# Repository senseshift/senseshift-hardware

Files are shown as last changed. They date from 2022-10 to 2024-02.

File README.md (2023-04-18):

# SenseShift Hardware

> Hardware Schematics for [SenseShift Firmware](https://github.com/senseshift/senseshift-firmware)




## Guides

We provide a variety of different step-by-step guides, made by our community, on our [Documentation](https://senseshift.github.io/guides/getting-started)!

## Schematics

> Each configuration have it's own BOM and wiring diagram

### Haptic Vest

#### X16 Haptic Vest

> Supported devices: **TactSuit X16**

* [X16 Vest with PCA9685](Devices/X16%20Vest/ESP32%20%2B%20PCA9685/)
* [X16 Vest without PCA9685](Devices/X16%20Vest/ESP32%20%2B%20Integrated%20PWM/)

#### X40 Haptic Vest

> Supported devices: **TactSuit X40**, **Tactot**

* [X40 Vest with x2 PCA9685](Devices/X40%20Vest/ESP32%20%2B%20x2%20PCA9685%20%2B%20Integrated%20PWM/)

### Haptic Glove

> Supported devices: **TactGloves**

* [x6 Haptic Glove](Devices/Haptic%20Gloves/ESP32%20%2B%20Integrated%20PWM/)

### Haptic Face Interface

> Supported devices: **Tactal**

* [x6 Facial Interface](Devices/Face%20Interface/ESP32%20+%20Integrated%20PWM/)

### Haptic Forearm Sleeve

> Supported devices: **Tactosy for Arms**

* [x6 Forearm Sleeve](Devices/Forearm%20Sleeves/ESP32%20+%20Integrated%20PWM/)

### Haptic Gauntlet

> Supported devices: **Tactosy for Hands**

* [x3 Hand Gauntlet](Devices/Hand%20Gauntlets/ESP32%20+%20Integrated%20PWM/)

### Haptic Feet Device

> Supported devices: **Tactosy for Feet**

* [x3 Feet Device](Devices/Feet%20Devices/ESP32%20+%20Integrated%20PWM/)

## SenseShift PCBs

PCBs are currently stored in [`feature/haptic-boards`](https://github.com/senseshift/senseshift-hardware/tree/feature/haptic-boards) branch (See PR [#3](https://github.com/senseshift/senseshift-hardware/pull/3)). Those designsed haven't been tested and will be merged, as soon as they are confirmed to be working 100%

## Licenses



Each project directory has it's own `LICENSE` file inside and licensed under corresponding license. Otherwise, if no `LICENSE` file is provided, it is licensed under [CC-BY-SA-4.0](https://creativecommons.org/licenses/by-sa/4.0/) license

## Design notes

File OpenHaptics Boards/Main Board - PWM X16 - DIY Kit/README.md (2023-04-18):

# SenseShift Mainboard *with X16 PWM*

> **Warning**  
> **Disclaimer:** This design is a **functional prototype**, not a complete product. There is absolutely no warranty, and you will make this design at your OWN risk. I will not be responsible for any damages associated with this design.

## Schematic

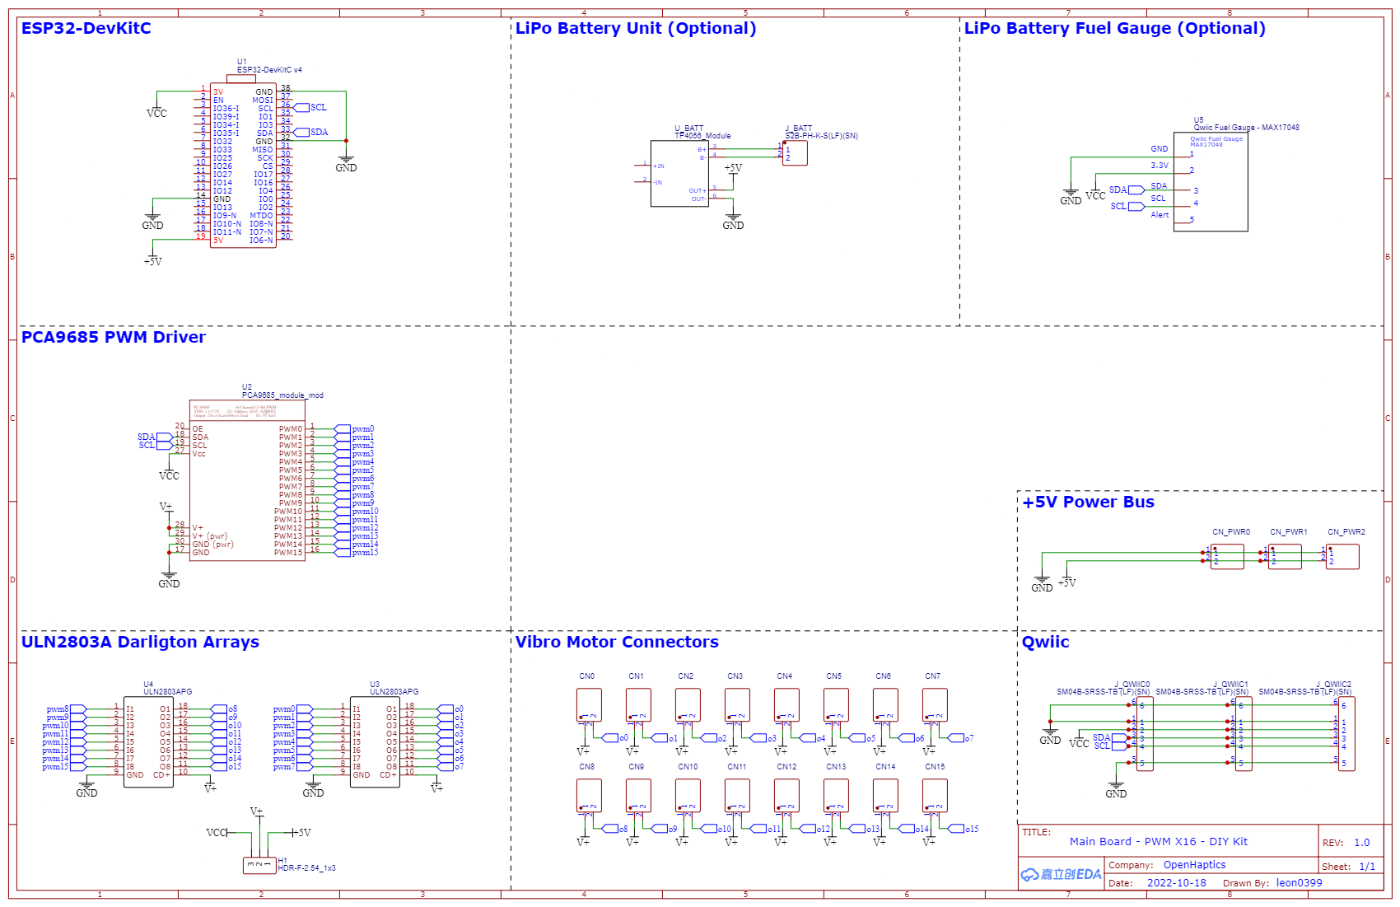
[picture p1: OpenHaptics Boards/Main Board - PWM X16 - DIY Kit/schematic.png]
Ciruit


## Licenses



This design is shared under [CC0 1.0](https://creativecommons.org/publicdomain/zero/1.0/) license

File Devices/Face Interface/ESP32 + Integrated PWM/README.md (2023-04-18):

# X6 Facial Haptic Interface

> X6 Facial Haptic Interface with 3V/5V vibro motors, optionally powered by LiPo battery

> **Warning**  
> **Disclaimer:** This design is a **functional prototype**, not a complete product. There is absolutely no warranty, and you will make this design at your OWN risk. I will not be responsible for any damages associated with this design.

## Compatible Devices

* Tactal

## Guides:

* Official [Build Guide](https://senseshift.github.io/guides/face-interface/esp32-breadboard)

## Bill of materials

| Component | Quantity | Price | Link  |
| :--- | ---: | ---: | :---- |
| `ESP32-DevKitC` | x1 | ~US $1.3 | `n/a` |
| `ULN2803A` | x1 | ~US $0.3 | `n/a` |
| 3V/5V Vibro Motors | x6 | ~US $1.1 | `n/a` |
| `TP4056` (Optional) | x1 | ~US $0.3 | `n/a` |
| `MT3608` (Optional) | x1 | ~US $0.4 | `n/a` |
| LiPo Battery (Optional) | x1 | ~US $7.0 | `n/a` |
| `MAX17043` or `MAX17048` Fuel Gauge (Optional) | x1 | ~US $5 | `n/a` |

## Schematic

### Required Pins

* PWA pins: `32`, `33`, `25`, `26`, `27`, `14`
* SDA: `21`
* SCL: `22`

### Wiring Diagram

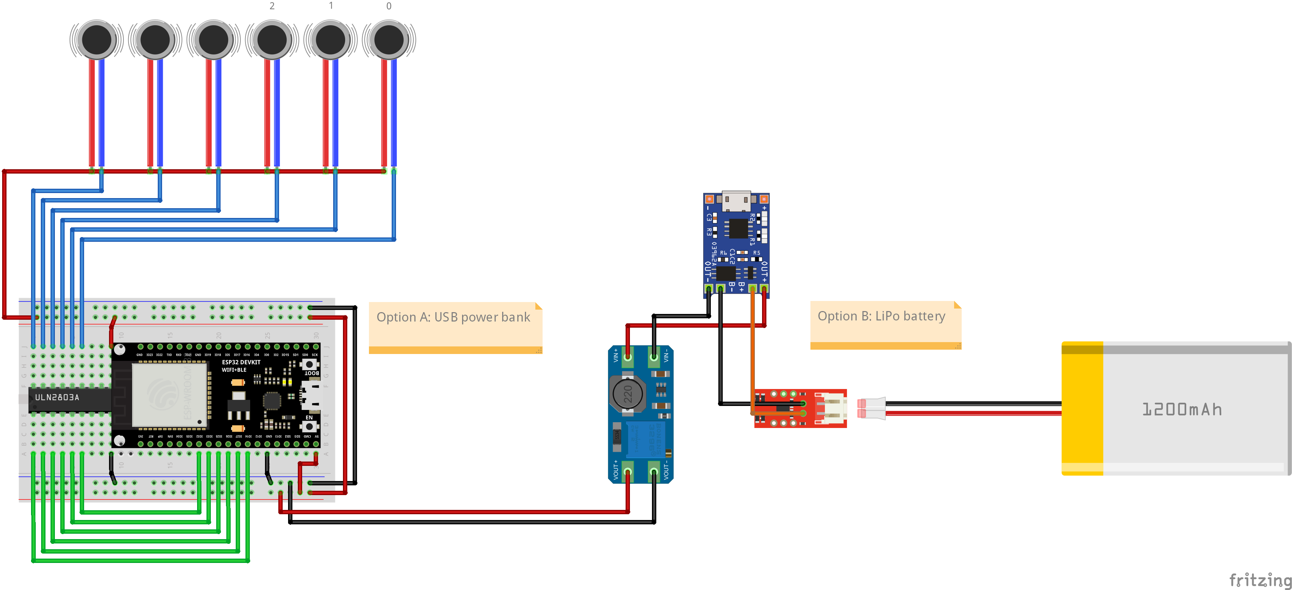
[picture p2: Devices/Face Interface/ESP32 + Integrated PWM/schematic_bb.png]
Schematic


> Please note motor indices

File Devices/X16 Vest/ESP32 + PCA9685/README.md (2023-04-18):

# X16 Haptic Vest

> X16 Haptic Vest with 3V/5V vibro motors, optionally powered by LiPo battery

> **Warning**  
> **Disclaimer:** This design is a **functional prototype**, not a complete product. There is absolutely no warranty, and you will make this design at your OWN risk. I will not be responsible for any damages associated with this design.

## Compatible Devices

* TactSuit X16

## Bill of materials

| Component | Quantity | Price | Link  |
| :--- | ---: | ---: | :---- |
| `ESP32-DevKitC` | x1 | ~US $1.3 | `n/a` |
| `PCA9685` PWM Driver | x1 | ~US $3.0 | `n/a` |
| `ULN2803A` | x2 | ~US $0.3 | `n/a` |
| 3V/5V Vibro Motors | x16 | ~US $1.1 | `n/a` |
| `TP4056` (Optional) | x1 | ~US $0.3 | `n/a` |
| `MT3608` (Optional) | x1 | ~US $0.4 | `n/a` |
| LiPo Battery (Optional) | x1 | ~US $7.0 | `n/a` |
| `MAX17043` or `MAX17048` Fuel Gauge (Optional) | x1 | ~US $5 | `n/a` |

## Schematic

### Required Pins

* SDA: `21`
* SCL: `22`

### Wiring Diagram

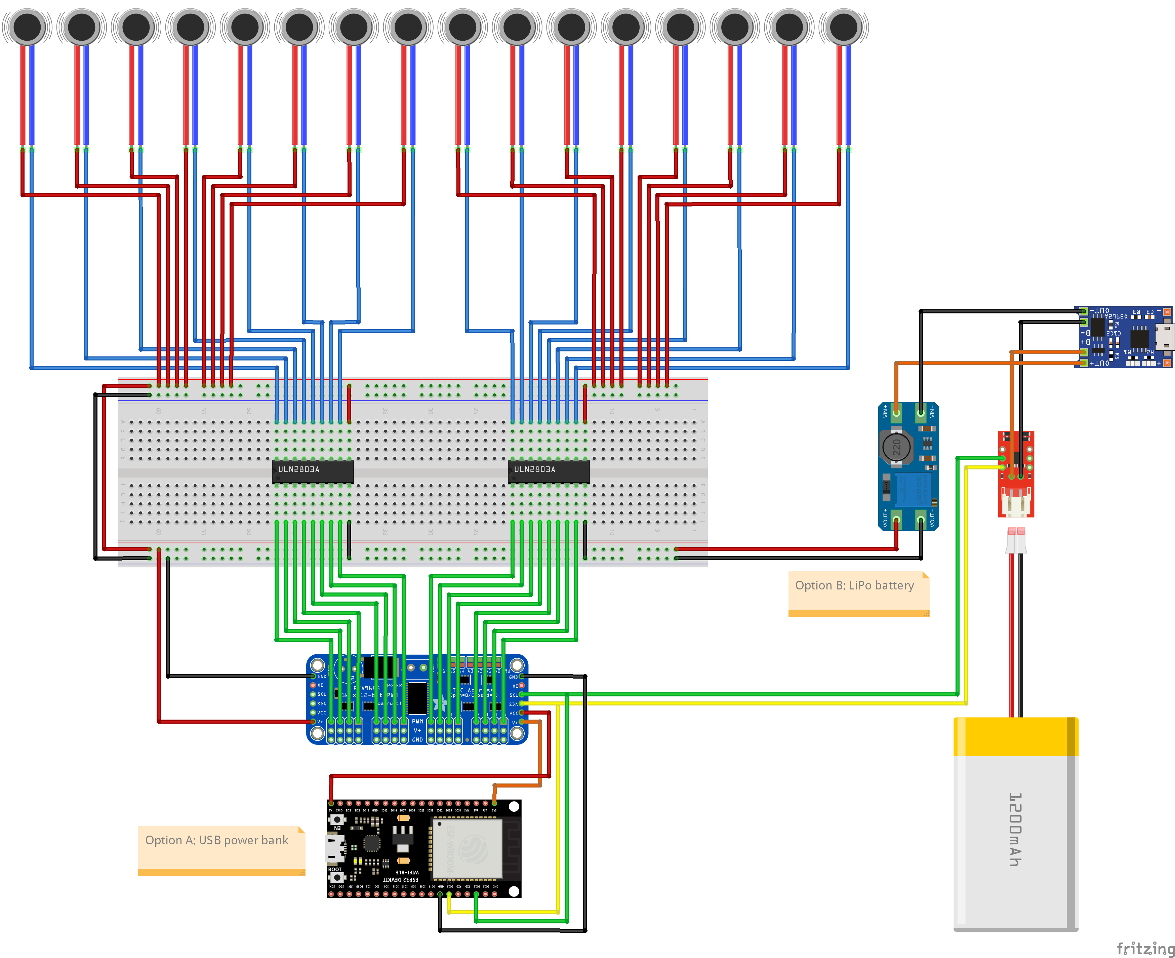
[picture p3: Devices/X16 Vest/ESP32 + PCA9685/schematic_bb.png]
Schematic


### Circuit Diagram

> See [Main Board - PWM X16 - DIY Kit](../../SenseShift%20Boards/Main%20Board%20-%20PWM%20X16%20-%20DIY%20Kit/) for full hardware

Ciruit

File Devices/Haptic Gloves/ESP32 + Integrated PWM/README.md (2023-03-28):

# X6 Haptic Glove

> Single X6 Haptic Glove with 3V/5V vibro motors, optionally powered by LiPo battery.

> **Warning**  
> **Disclaimer:** This design is a **functional prototype**, not a complete product. There is absolutely no warranty, and you will make this design at your OWN risk. I will not be responsible for any damages associated with this design.

## Compatible Devices

* TactGloves

## Bill of materials

This list id for single glove, you most likely will need 2x.

| Component | Quantity | Price | Link  |
| :--- | ---: | ---: | :---- |
| `ESP32-DevKitC` | x1 | ~US $1.3 | `n/a` |
| `ULN2803A` | x1 | ~US $0.3 | `n/a` |
| 3V/5V Vibro Motors | x6 | ~US $1.1 | `n/a` |
| `TP4056` (Optional) | x1 | ~US $0.3 | `n/a` |
| `MT3608` (Optional) | x1 | ~US $0.4 | `n/a` |
| LiPo Battery (Optional) | x1 | ~US $7.0 | `n/a` |
| `MAX17043` or `MAX17048` Fuel Gauge (Optional) | x1 | ~US $5 | `n/a` |

## Schematic

### Required Pins

* PWA pins: `32`, `33`, `25`, `26`, `27`, `14`
* SDA: `21`
* SCL: `22`

### Wiring Diagram

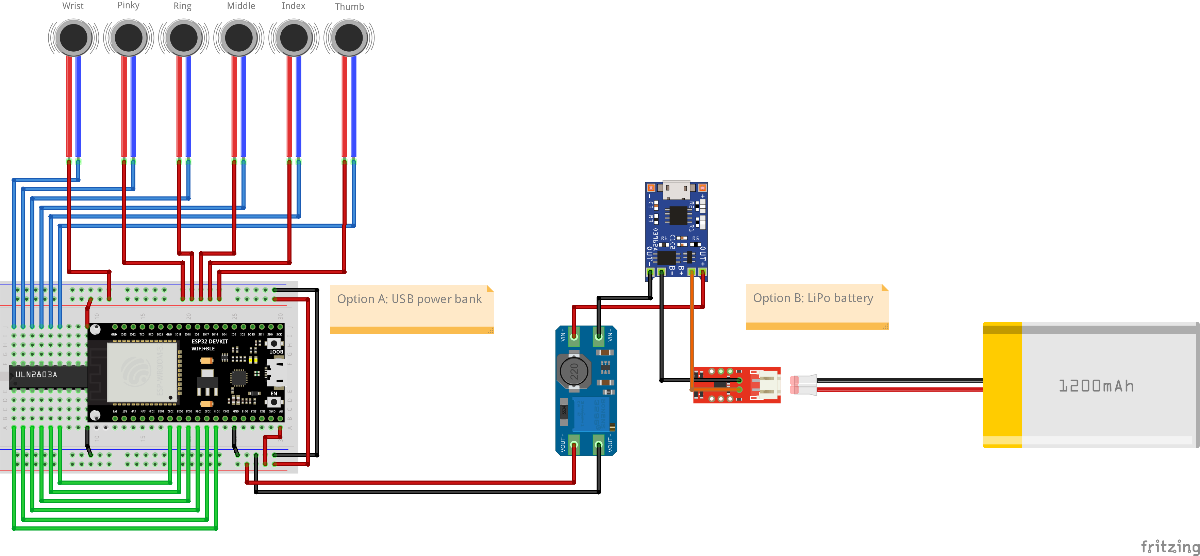
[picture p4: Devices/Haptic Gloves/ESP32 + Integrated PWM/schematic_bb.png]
Schematic


> Please note motor indices

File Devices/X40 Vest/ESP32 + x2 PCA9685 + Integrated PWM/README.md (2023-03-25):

# X40 Haptic Vest

> X40 Haptic Vest with 3V/5V vibro motors, optionally powered by LiPo battery

> **Warning**  
> **Disclaimer:** This design is a **functional prototype**, not a complete product. There is absolutely no warranty, and you will make this design at your OWN risk. I will not be responsible for any damages associated with this design.

## Compatible Devices

* TactSuit X40, Tactot

## Guides:

* [Build Guide](https://docs.google.com/document/d/1j84h-7OIkRO9KTNtq_mKxri_7PsSNUnL/view) by ProBendingVR

## Bill of materials

| Component | Quantity | Price | Link  |
| :--- | ---: | ---: | :---- |
| `ESP32-DevKitC` | x1 | ~US $1.3 | `n/a` |
| `PCA9685` PWM Driver | x2 | ~US $3.0 | `n/a` |
| `ULN2803A` | x5 | ~US $0.3 | `n/a` |
| 3V/5V Vibro Motors | x40 | ~US $1.1 | `n/a` |
| `TP4056` (Optional) | x1 | ~US $0.3 | `n/a` |
| `MT3608` (Optional) | x1 | ~US $0.4 | `n/a` |
| LiPo Battery (Optional) | x1 | ~US $7.0 | `n/a` |
| `MAX17043` or `MAX17048` Fuel Gauge (Optional) | x1 | ~US $5 | `n/a` |

## Schematic

### Required Pins

* SDA: `21`
* SCL: `22`
* PWA pins: `32`, `33`, `25`, `26`, `27`, `14`, `13`

### Wiring Diagram

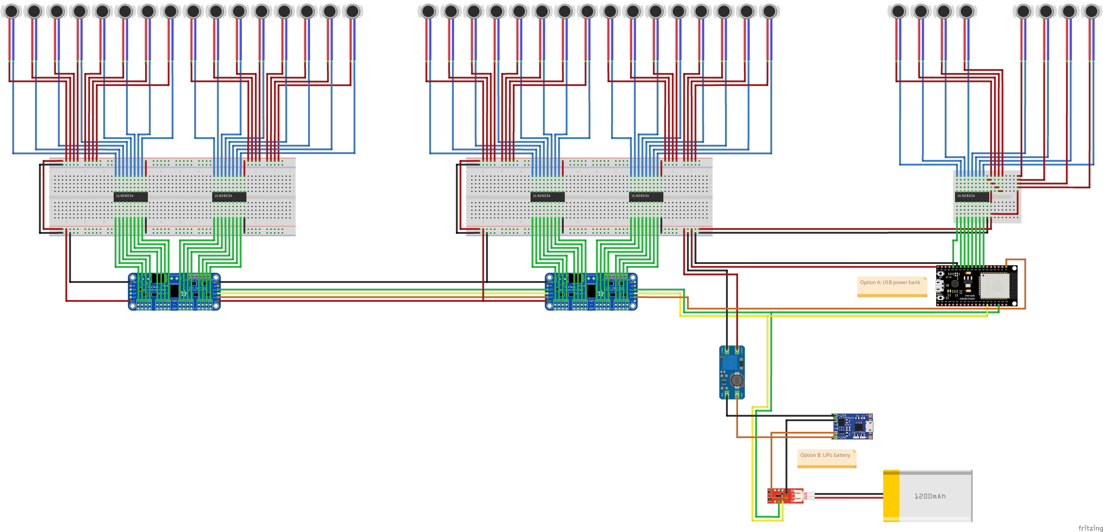
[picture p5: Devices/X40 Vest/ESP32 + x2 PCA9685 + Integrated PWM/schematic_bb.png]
Schematic


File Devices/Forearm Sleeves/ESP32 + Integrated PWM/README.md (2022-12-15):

# X6 Haptic Forearm Sleeve

> X6 Haptic Forearm Sleeve with 3V/5V vibro motors, optionally powered by LiPo battery

> **Warning**  
> **Disclaimer:** This design is a **functional prototype**, not a complete product. There is absolutely no warranty, and you will make this design at your OWN risk. I will not be responsible for any damages associated with this design.

## Compatible Devices

* Tactosy for Arms

## Bill of materials

> **Note**  
> Following table is for a single device, and you most likely will require 2 of them

| Component | Quantity | Price | Link  |
| :--- | ---: | ---: | :---- |
| `ESP32-DevKitC` | x1 | ~US $1.3 | `n/a` |
| `ULN2803A` | x1 | ~US $0.3 | `n/a` |
| 3V/5V Vibro Motors | x6 | ~US $1.1 | `n/a` |
| `TP4056` (Optional) | x1 | ~US $0.3 | `n/a` |
| `MT3608` (Optional) | x1 | ~US $0.4 | `n/a` |
| LiPo Battery (Optional) | x1 | ~US $7.0 | `n/a` |
| `MAX17043` or `MAX17048` Fuel Gauge (Optional) | x1 | ~US $5 | `n/a` |

## Schematic

### Required Pins

* PWA pins: `32`, `33`, `25`, `26`, `27`, `14`
* SDA: `21`
* SCL: `22`

### Wiring Diagram

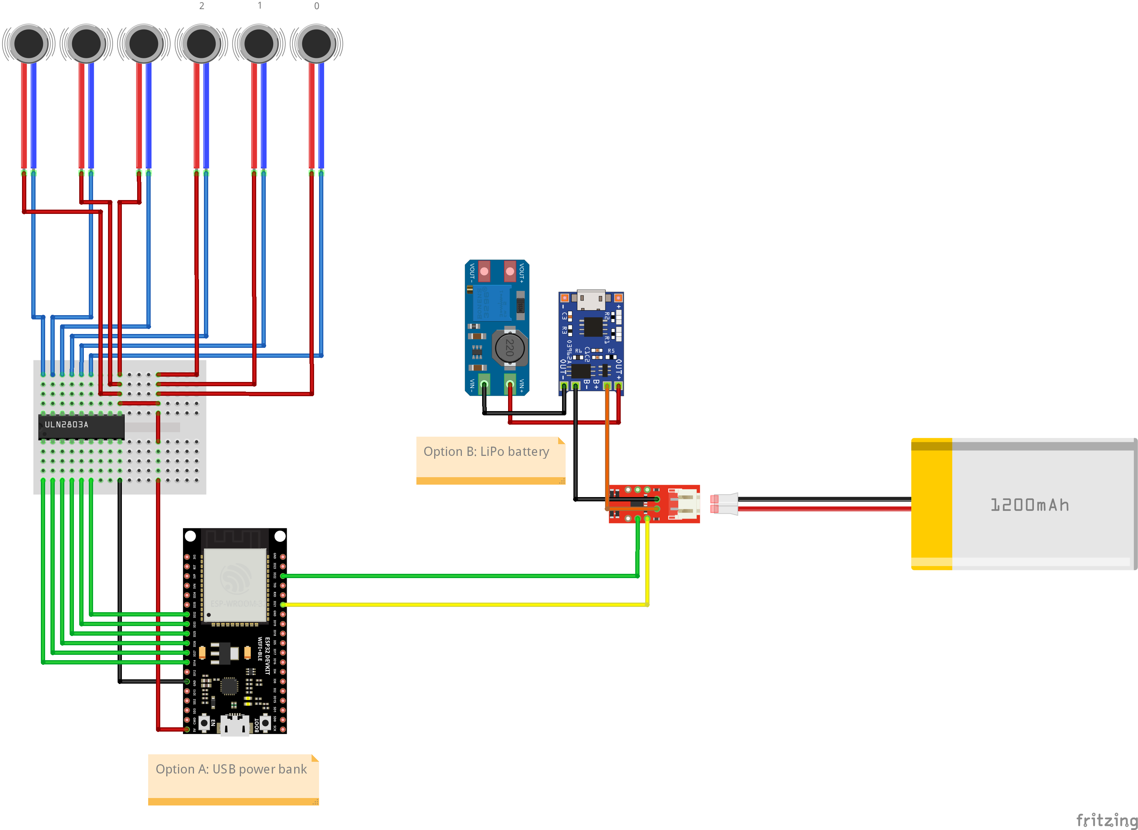
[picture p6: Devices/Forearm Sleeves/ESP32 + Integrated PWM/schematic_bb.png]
Schematic


> Please note motor indices

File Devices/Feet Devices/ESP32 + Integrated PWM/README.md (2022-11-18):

# X3 Haptic Feet Device

> X3 Haptic Feet Device with 3V/5V vibro motors, optionally powered by LiPo battery

> **Warning**  
> **Disclaimer:** This design is a **functional prototype**, not a complete product. There is absolutely no warranty, and you will make this design at your OWN risk. I will not be responsible for any damages associated with this design.

## Compatible Devices

* Tactosy for Feet

## Bill of materials

> **Note**  
> Following table is for a single device, and you most likely will require 2 of them

| Component | Quantity | Price | Link  |
| :--- | ---: | ---: | :---- |
| `ESP32-DevKitC` | x1 | ~US $1.3 | `n/a` |
| `ULN2803A` | x1 | ~US $0.3 | `n/a` |
| 3V/5V Vibro Motors | x3 | ~US $1.1 | `n/a` |
| `TP4056` (Optional) | x1 | ~US $0.3 | `n/a` |
| `MT3608` (Optional) | x1 | ~US $0.4 | `n/a` |
| LiPo Battery (Optional) | x1 | ~US $7.0 | `n/a` |
| `MAX17043` or `MAX17048` Fuel Gauge (Optional) | x1 | ~US $5 | `n/a` |

## Schematic

### Required Pins

* PWA pins: `32`, `33`, `25`
* SDA: `21`
* SCL: `22`

### Wiring Diagram

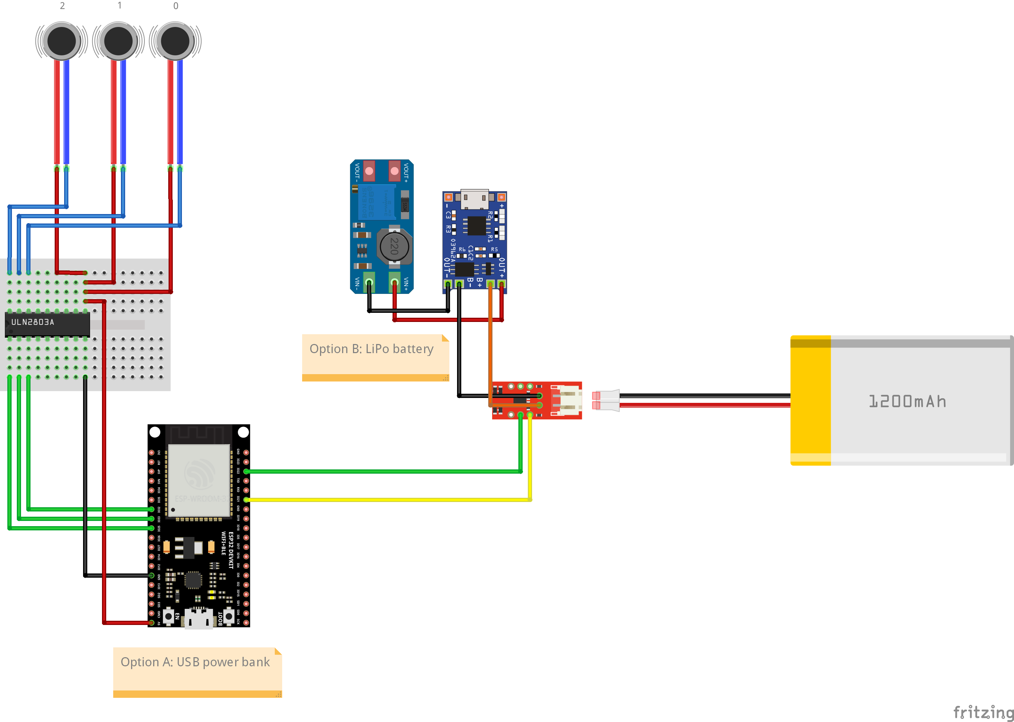
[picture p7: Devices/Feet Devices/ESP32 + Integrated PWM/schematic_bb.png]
Schematic


> Please note motor indices

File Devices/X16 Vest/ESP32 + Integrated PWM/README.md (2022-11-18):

# X16 Haptic Vest

> X16 Haptic Vest with 3V/5V vibro motors, optionally powered by LiPo battery

> **Warning**  
> **Disclaimer:** This design is a **functional prototype**, not a complete product. There is absolutely no warranty, and you will make this design at your OWN risk. I will not be responsible for any damages associated with this design.

## Compatible Devices

* TactSuit X16

## Bill of materials

| Component | Quantity | Price | Link  |
| :--- | ---: | ---: | :---- |
| `ESP32-DevKitC` | x1 | ~US $1.3 | `n/a` |
| `ULN2803A` | x2 | ~US $0.3 | `n/a` |
| 3V/5V Vibro Motors | x16 | ~US $1.1 | `n/a` |
| `TP4056` (Optional) | x1 | ~US $0.3 | `n/a` |
| `MT3608` (Optional) | x1 | ~US $0.4 | `n/a` |
| LiPo Battery (Optional) | x1 | ~US $7.0 | `n/a` |
| `MAX17043` or `MAX17048` Fuel Gauge (Optional) | x1 | ~US $5 | `n/a` |

## Schematic

### Required Pins

* PWA pins: `32`, `33`, `25`, `26`, `27`, `14`, `12`, `13`, `19`, `18`, `5`, `17`, `16`, `4`, `2`, `15`
* SDA: `21`
* SCL: `22`

### Wiring Diagram

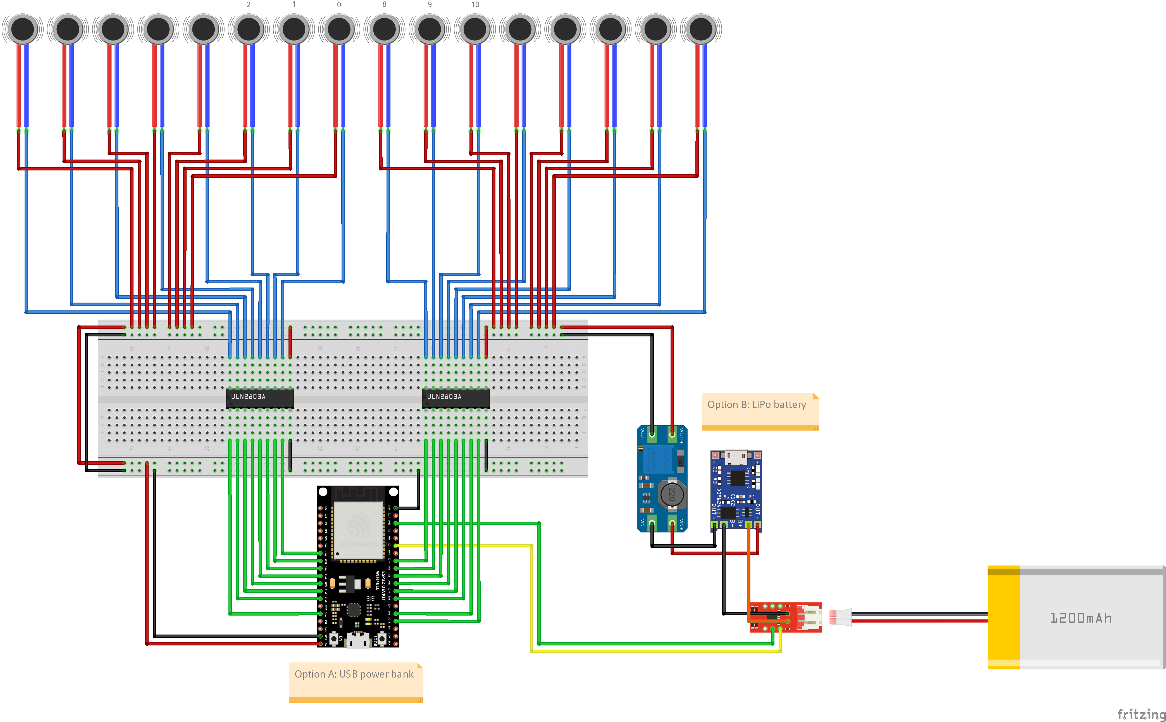
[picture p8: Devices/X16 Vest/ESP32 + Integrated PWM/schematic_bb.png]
Schematic


> Please note motor indices

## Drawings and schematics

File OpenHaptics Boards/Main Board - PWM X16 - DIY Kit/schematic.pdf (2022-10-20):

# ESP32-DevKitC

LiPo Battery Unit (Optional) | LiPo Battery Fuel Gauge (Optional)

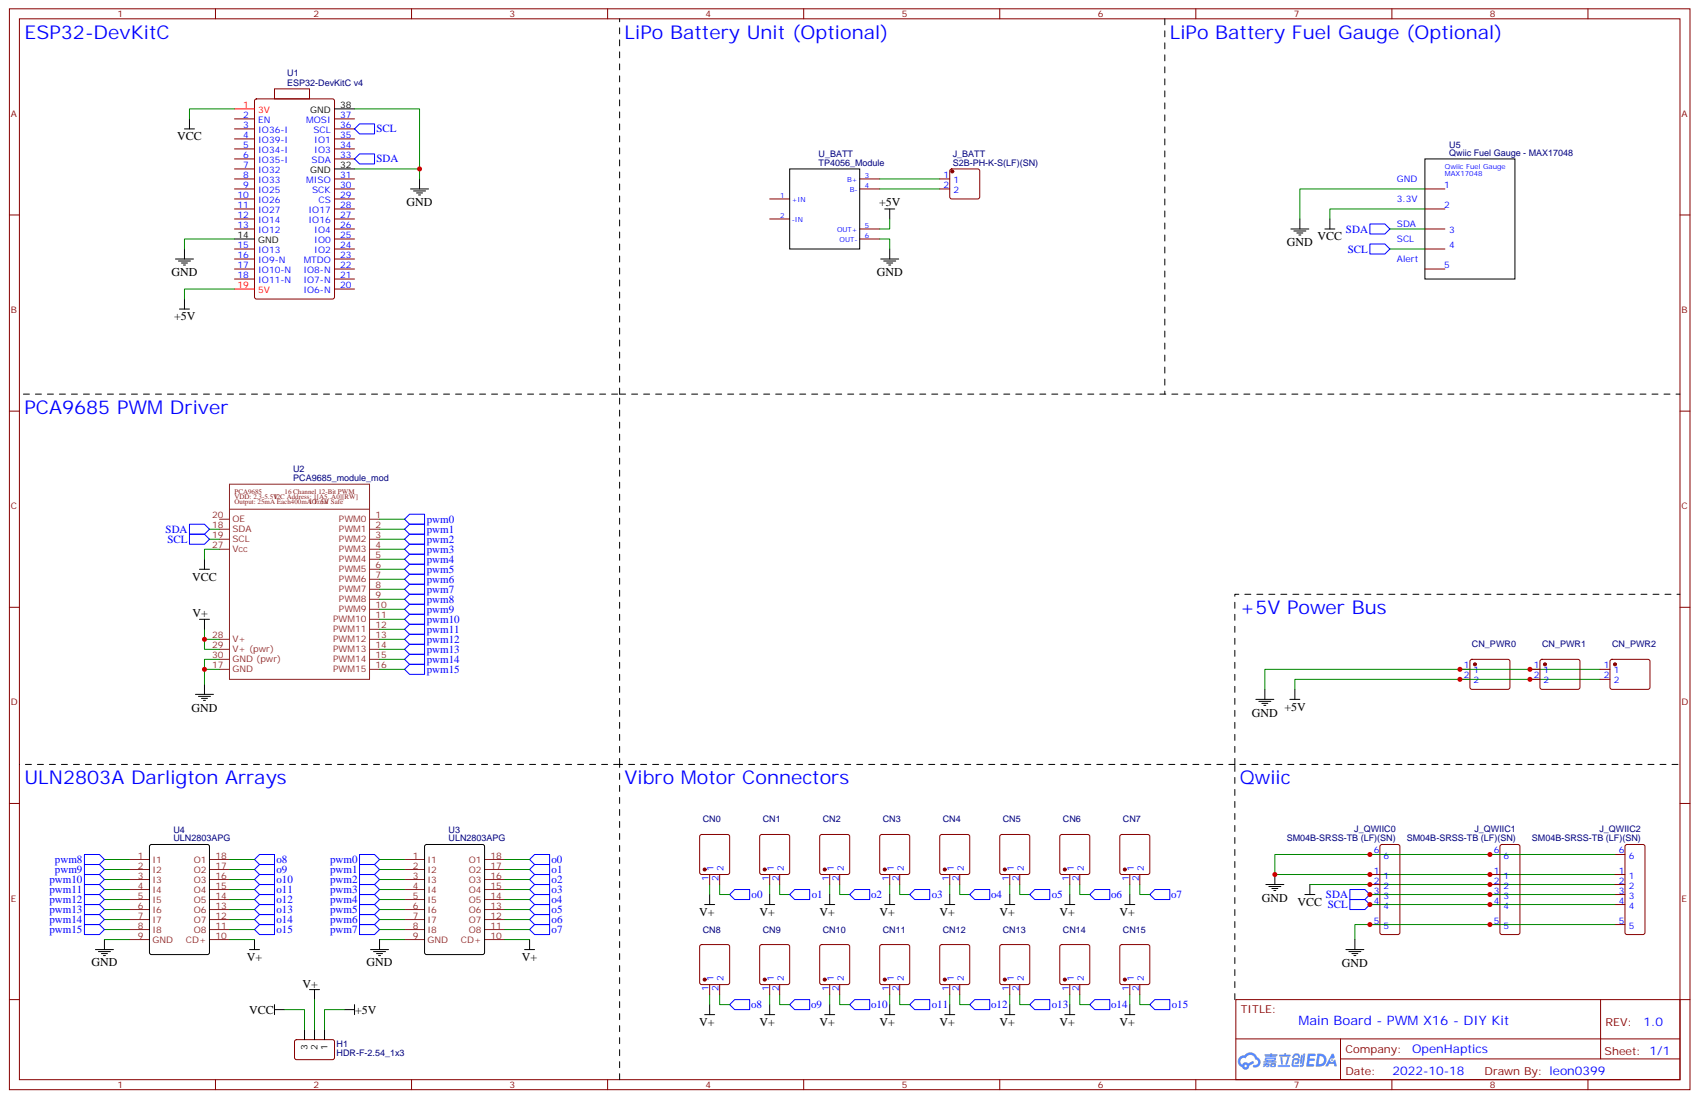
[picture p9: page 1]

SM04B-SRSS-TB (LF)(SN)

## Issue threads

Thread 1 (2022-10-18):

[WIP] [RFC] Hardware Options

leon0399, 2022-10-18:
> Main idea is to create affordable infrastructure to allow wide variety of options to build OpenHaptics devices

## Main Board

Main Board is a core device, that child boards are connected to.
Has x3 **I2C Bus Wires**, LiPo battery unit circuit (charger and gauge),

1. **DIY Kit Board**. `ESP32-DevKit-V4` mounted with 2.54mm female headers. Intended to use with DIY Kits
2. **SMD Board**. Built with `ESP32-WROOM-32E`

## PWM Boards

PWM Board used to connect PWM-controlled vibro-motors for basic haptic feedback

1. **X16 PWM Board**. Built with `PCA9685` and x2 `ULN2803A`, has x2 **I2C Bus Wires**
2. **X8 PWM Board**. Built with `PCA9685` and x1 `ULN2803A`, has x1 **I2C Bus Wires**, used for smaller applications (hands, etc.)

## Haptic Board

Haptic Board is used to drive LRAs or compatible ERMs for more advanced haptic feedback

1. **Single-unit Haptic Board**. Built with `DRV2605L`, has x4 **I2C Bus Wires** for matrix-like connection
2. `TODO`

## Reusable Component

1. **I2C Bus Wire**: Have 3x 6-pin Wire To Wire connectors (`GND`, `SDA`, `SCL`, `OE`, `+3.3V`, `+5V`)
2. `TODO`

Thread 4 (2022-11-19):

Potential small error in x40 schematic

ivo1981, 2022-11-19:
I think there's a +5v missing (com pin 10) on the most right uln2803
(The one connected directly to the esp

leon0399, 2022-11-19:
Thank you! Yes, I've re-checked, and there is indeed an issue: I've missed one vibro motor (You can count only 7 motors attached to uln2803)
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

ivo1981, 2022-11-19:
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
Here also

leon0399, 2022-11-19:
Ah, ok! Thank you!

ivo1981, 2022-11-19:
You're welcome! I will be building a tactile later this week to try stuff out and then a x40. Thanks for the great work so far!

leon0399, 2022-11-19:
> You're welcome! I will be building a tactile later this week to try stuff out and then a x40. Thanks for the great work so far!

Good luck! And consider sharing your results with us in discord 😉

ivo1981, 2022-11-19:
Ah sure! I'll join now!

Closed 2022-11-19.

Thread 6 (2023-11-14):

mistake into the shematics

StasMK, 2023-11-14:
In the shematics, the left vibration motors are connected only with blue wires. And they should be red (+) and blue (-)

Closed 2024-02-08.

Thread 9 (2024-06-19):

Diagram issue. X16Vest with power connections...

walterleonardo, 2024-06-19:
[X16 Vest with PCA9685](https://github.com/senseshift/senseshift-hardware/blob/main/Devices/X16%20Vest/ESP32%20%2B%20PCA9685)
[X16 Vest without PCA9685](https://github.com/senseshift/senseshift-hardware/blob/main/Devices/X16%20Vest/ESP32%20%2B%20Integrated%20PWM)

This connection must be reversed... the +v has to go to the regulated input of the ESP since it can go up to +6 volts. And the VCC pin has to be connected to the 3.3Volts output on the ESP, to power the logic part.
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

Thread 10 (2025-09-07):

Issue with the X16 Haptic Vest (the one without the PCA9685)

AxxMnn, 2025-09-07:
The diagram for the X16 Haptic Vest (the one without the PCA9685) has pin11 (marked on some boards as CMD) hooked into ground. I'm assuming someone misread it as GND (since the wire is also black), unless they know some secret voodoo ninja shit. Pin11 (CMD) is reserved for the internal flash memory and according to most documentation should never be used as it could potentially interfere with reading/writing to flash.

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

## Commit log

2022-10-11 feat(Vest): add X16 5V LiPo
    [schematic.fzz]
2022-10-11 fix(Vest): x16 motors BOM
2022-10-19 feat: add Main Board PWM X16 DIY Kit PCB
    [schematic.fzz]
2022-10-19 chore(Vest): update schematics
    [schematic.fzz]
2022-10-19 chore: rename directories
    [schematic.fzz]
2022-10-19 feat(Vest): add symlink for x16 DIY Kit board
2022-10-19 feat(Vest): add X16 DIY readme and BOM
    [schematic.fzz]
2022-10-19 feat: add DIY Main Board PWM x16 EasyEDA sources
2022-10-19 feat(Vest): add options for battery
    [schematic.fzz]
2022-10-20 feat: use Qwiic connector as main bus
2022-10-20 chore: update breadboard
    [schematic.fzz]
2022-11-10 refactor: rename folders, add fuel gauge
    [schematic.fzz]
2022-11-16 feat(Devices): add haptic sleeve, gauntlet, feet device and facial interface schematics (#2)
    * refactor: create dedicated dir for devices
    * feat(Devices): add Haptic Facial Interface
    * docs: update devices description
    * feat(Devices): add forearm sleeve
    * feat(Devices): add X3 Haptic Gauntlet
    * fix(Devices): missing wire on face and sleeve
    * docs: add links to all devices
    * feat(Devices): add haptic feet devices
    * docs: fix readme gauntlet title
    [schematic.fzz]
2022-11-18 feat(Devices): add X40 Vest schematic
    [schematic.fzz]
2022-11-18 fix(Boards): x16 mainboard links
2022-11-19 fix(VestX40): missing wires in schematic
    Fixes #4
    [schematic.fzz]
2022-11-26 feat: add Folder for 3D printed models
2022-12-15 docs(Devices): correct Sleeve compatible devices
2023-01-06 feat(Devices): update face interface wiring
    [schematic.fzz]
2023-03-25 feat: add links to documentation and guides
    [schematic.fzz]
2023-03-28 feat(Gloves): add x6 Haptic Glove
    Close #5
    [schematic.fzz]
2024-02-08 fix(Boards): incorrect wire colors
    Fixed #6
    [schematic.fzz]
